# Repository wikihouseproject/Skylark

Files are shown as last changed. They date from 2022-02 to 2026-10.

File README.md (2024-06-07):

# Skylark
A block-based WikiHouse timber building system, developed for 1-3 storey construction.
For more information, product guides, and support services please visit www.wikihouse.cc

#### This work is licensed under a <a rel="license" href="http://creativecommons.org/licenses/by-sa/4.0/">Creative Commons Attribution-ShareAlike 4.0 International License</a>.

Developed and maintained by the friendly team at Open Systems Lab (www.opensystemslab.io).

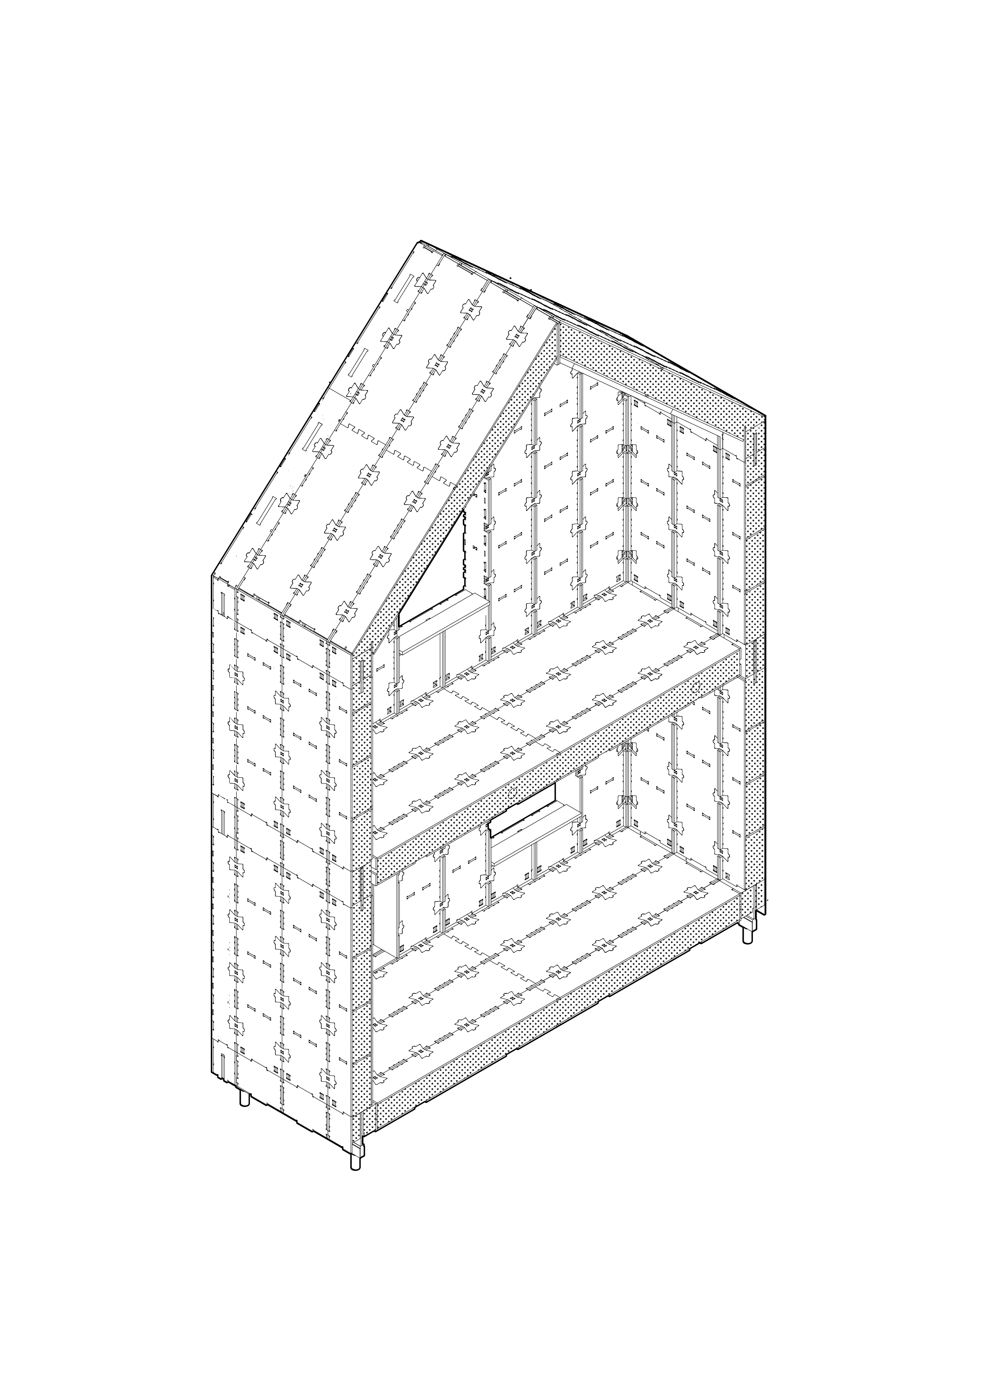
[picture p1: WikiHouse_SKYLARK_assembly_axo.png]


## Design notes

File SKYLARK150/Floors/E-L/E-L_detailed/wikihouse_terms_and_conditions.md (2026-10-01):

# WikiHouse Skylark Blocks — CNC Manufacturing Files

## WikiHouse Skylark System

**Website:** [www.wikihouse.cc](https://www.wikihouse.cc)
Developed by **Open Systems Lab**

> By using this information you agree to the full WikiHouse Terms of Use:
> [https://www.wikihouse.cc/terms](https://www.wikihouse.cc/terms)

---

## CNC Information

All geometry has tolerance offsets pre-applied for manufacture. "Dog-bone" pockets have been added on internal corners to mitigate any filleting caused by the router bit. Follow the layer information below for guidance on recommended settings.

---

## Layer Information

| Layer | Description |
|---|---|
| `DONOTCUT` | Information for instruction purposes only |
| `0_SHEET_SPRUCEPLY_2440X1220X18` | Plywood material boundary for reference |
| `1_ANYTOOL_1MMDEEP_LABELS` | Text labels — convert to curves and engrave at 1 mm depth |
| `2_ANYTOOL_1MMDEEP_SCREWMARKS` | Marker "dinks" for nails/screws during assembly — pre-mark using 2–3 mm bit |
| `3_ANYTOOL_CUTTHROUGH_INSIDE` | Internal slots — cut through inside line |
| `4_ANYTOOL_CUTTHROUGH_OUTSIDE` | External profile of parts — cut through outside line |
| `5_ANYTOOL_HALF_MILL_9MM_INSIDE` | Mill out area to 9 mm depth |

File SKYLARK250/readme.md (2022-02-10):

# Skylark 250 series
Skylark 250 is the main WikiHouse building system. The structure is deep enough to contain 250mm of wall insulation and it is intended for use in 1-3 storey detached buildings. For more information, view the design guide (https://www.wikihouse.cc/guides/design).

BY USING THIS INFORMATION YOU AGREE 
TO THE FULL WIKIHOUSE TERMS OF USE:
https://www.wikihouse.cc/terms

WikiHouse information and files are shared ‘as is’, without warranties, guarantees or certifications of any kind, express or implied. This includes, without limitation, warranties that the content is accurate, complete, free of defects, fit for a particular purpose or non-infringing in relation to the use of WikiHouse information or the results of such use. You are wholly responsible for checking WikiHouse information and for using WikiHouse information in a safe way, and for satisfying yourself that you meet all relevant regulations, including planning regulations, building codes and health & safety legislation; as well as for working with appropriate equipment and materials and appropriately competent persons. Every project should always be checked by a structural engineer. For more specific advice, the End User should engage relevant qualified professionals or competent persons.

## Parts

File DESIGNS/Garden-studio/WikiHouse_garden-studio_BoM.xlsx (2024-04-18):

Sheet: Garden room BoM (standard)
Project name
Customer name
Project status
Delivery address
Building Type | Garden room |  |  |  |  | Key: | Materials
Gross Internal Area (m2) | 10.8 |  |  |  |  |  | Labour
Updated | 2024-04-15
Note: This is a template for project estimation purposes only. Specified items listed here are subject to prices changes, and these figures do not represent a quote or guaranteed build price.
Bill of Materials
 | Description | Suggested specification | Total quantity | Unit | Cost per unit | Total cost | Est. mass (kg) | Embodied CO2 (kgCOe)
FOUNDATIONS
Piles | 1000mm round ground screws, securing L brackets | Self-installed ground screws (https://thegroundscrewshop.co.uk/calculator/) | 18 | No. | £30.00 | £540 | - | -
Base frame / sole plate | 200x75mm C24 timber joist | 200x75 (195x72mm finished size) C24 treated timber joist (https://www.stoketimber.com/product/75-x-200-69-x-195-finished-sizes-treated-c16-grade-timber-joists/) | 14.4 | m | £10.00 | £144 | - | -
Timber decking | Non-slip treated softwood decking | TBC | 5 | m2 | £70.00 | £350 | 60 | -61.8
Deck base frame | C24 timber joists | 100x50mm c24 treated timber joists | 22.5 | m | £8.00 | £180 | - | -
Piles to support deck | 800mm round ground screws, securing brackets | Self-installed ground screws (https://thegroundscrewshop.co.uk/calculator/) | 10 | No. | £30.00 | £300 | - | -
Foundation install |  |  |  | person/day |  | £0
Deck install |  |  |  | person/day |  | £0
 |  |  |  |  |  | £1514
STRUCTURE
WikiHouse chassis | 18mm OSB3 2440x1220mm sheets | SterlingOSB3 Zero | 70 | sheets | £19.00 | £1330 | 1953 | -3229.411248
Wall insulation | 200mm thick coverage soft-fill batts | Rockwool | 150 | m2 | £15.00 | £2250 | 600 | 78
Floor insulation | 150mm thick coverage soft-fill batts | Rockwool | 14.4 | m2 | £15.00 | £216 | 57.6 | 7.488
Under floor insulation | 40mm woodfibre board insulation | Pavatherm Pavatex 575x40mm | 10.08 | m2 | £15.00 | £151.2 | - | -
Roof insulation | 150mm thick coverage soft-fill batts | Rockwool | 14.4 | m2 | £15.00 | £216 | 57.6 | 7.488
Fixings | Brad nails for manufacturer | No. 18 brad nails 35mmx1.5mm | 4.4 | packs | £6.00 | £26.4 | - | -
CNC machining & manufacturing costs | By manufacturer | 3 axis CNC with 1.22 x 2.44m bed | 70 | sheets | £37.50 | £2625
Offsite Block assembly | By manufacturer |  | 2 | person/day | £200.00 | £400
Chassis assembly | By contractor/manufacturer |  |  | person/day |  | £0
 |  |  |  |  |  | £7214.6
SEAL
Breather membrane and tape | Weatherproof breather membrane | DuPont Tyvek UV Facade Protective Membrane (https://www.insulationsuperstore.co.uk/product/tyvek-uv-facade-protective-membrane-from-dupont-50m-x-15m-roll.html) | 55 | m2 | £6.00 | £330 | - | -
Airtight tape | Airtight vapour seal tape | Tescon or similar | 50 | m | £1.00 | £50 | - | -
Window | 600x1500mm double glazed tilt & turn | Pine frame double glazed (https://windowsarchitects.co.uk/product/configure/) | 1 | No. | £500.00 | £500 | 37 | -
External door | Timber frame double glazed french doors | w2400mm x h2000mm timber frame double glazed french doors | 1 | No. | £2200.00 | £2200 | 165 | -
Skylight | Double glazed fixed rooflight | 1300x400mm double glazed fixed rooflight | 1 | No. | £750.00 | £750 | - | -
EPDM roofing membrane | Dry-apply EPDM rubber membrane | 1.2mm EPDM rubber membrane single sheet (https://www.rubber4roofs.co.uk/classicbond-one-piece-epdm-rubber-roof-covering-1-20mm) | 15 | m2 | £11.00 | £165 | - | -
External membrane install |  |  |  | person/day |  | £0
Airtight tape install |  |  |  | person/day |  | £0
Window, door & rooflight install |  |  |  | person/day |  | £0
 |  |  |  |  |  | £3995
EXTERNAL FINISHES
Rainscreen cladding | Softwood vertical cladding boards | 50x25mm British larch cladding, planed | 35 | m2 | £60.00 | £2100 | 770 | -793.1
Cladding battens | Treated battens and counterbattens | 25mm x 50mm treated softwood (@600 ctrs) | 220 | m | £1.00 | £220 | 151.25 | -155.7875
Roofing material | Sedum blanket green roof system | Sky Garden sedum blanket system (https://www.roofingsuperstore.co.uk/product/sky-garden-sedum-blanket-system-kit-15m2.html) | 15 | m2 | £50.00 | £750 | - | -
Roofing edging | Aluminium sedum roof edging | 80mm high edge strip | 15.6 | m | £17.00 | £265.2 | - | -
Gutters | Steel half-round gutter | 100mm galvanised steel half-round | 5 | m | £15.00 | £75 | - | -
Downpipes | 2.5m steel round downpipe with header | 75mm galvanised steel downpipe (https://www.roofingmegastore.co.uk/lindab-steel-guttering-downpipe.html) | 5 | m | £35.00 | £175 | - | -
Window reveals | Softwood 100mm deep reveals | 100x20mm British larch cladding, planed | 20.4 | m | £5.00 | £102 | 28.05 | -28.8915
Flashings and accessories | Aluminium flashing and sealing tape | Aluminium window head flashing | 10 | m | £10.00 | £100 | - | -
Roofing install |  |  |  | person/day |  | £0
Cladding install |  |  |  | person/day |  | £0
 |  |  |  |  |  | £3787.2
SERVICES
Space heating | Electrical underfloor heating and thermostat | 150W/m2 system plus underlay and thermostat (10m2) (https://www.theunderfloorheatingstore.com/products/prowarm-electric-underfloor-heating-150w-mat-kit) | 1 | No. | £300.00 | £300 | - | -
Electrics and lighting | Garden room electrical kit | Fuse box, 2x double sockets, LED downlights, dimmer light switch | 1 | Configuration | £100.00 | £100 | - | -
External lighting | Up & down lights | Chrome external LED up & down lights | 2 | No. | £25.00 | £50 | - | -
PV solar system (Optional) | Optional solar PV system and inverter | TBC | 1 | No. |  | £0 | - | -
Electrical & heating install |  |  |  | person/day |  | £0
Solar panels install (Optional) |  |  |  | person/day |  | £0
 |  |  |  |  |  | £450
INTERNAL FIT OUT & FINISHES
Internal lining | 15mm woodwool lining boards | 2100mm x 600mm woodwool boards (https://www.savolit.co.uk/product/savolit-plus-woodwool-boards/) | 37.2 | m2 | £10.00 | £372 | - | -
Chipboard floor covering | 18mm tongue & groove flooring | Chipboard Tongue & groove Floorboard 2.4mx600mmx18mm (https://www.diy.com/departments/p5-tgv4-chipboard-tongue-groove-floorboard-l-2-4m-w-600mm-t-18mm/1696267_BQ.prd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) | 10.8 | m2 | £10.00 | £108 | - | -
Flooring | Engineered wood flooring | 14mm thick natural oak floating floor | 10.8 | m2 | £45.00 | £486 | - | -
Internal window reveals | 18mm plywood reveals | 200x18mm birch plywood reveals | 13 | m | £5.00 | £65 | - | -
Shelving & cabinetry | Optional custom 18mm plywood shelving unit | TBC | 1 | No. | £0.00 | £0 | 27.9 | -46.1344464
Flooring labour |  |  |  | person/day |  | £0
Internal finishes |  |  |  | person/day |  | £0
 |  |  |  |  |  | £1031
SELF-BUILD ESTIMATE (ex VAT)* |  |  |  |  |  | £17991.8 | 3907.4 | -4222.148694
Contingency (10%) |  |  |  |  |  | £1799.18
INSTALL ESTIMATE (ex VAT)* |  |  |  |  |  | £0 | kg | kgCO2e
TOTAL ESTIMATE* |  |  |  |  |  | £19790.98
VAT |  |  |  |  |  | £3958.196
*Build estimates for materials and labour, excluding VAT, fees, profits, overheads, contractor's prelims, transportation and landscaping

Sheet: Garden room blocks list (standa
Project name
Customer name
Delivery address
Skylark Cutting List Estimate
Name | Skylark_series | Type | Latest release | No. of blocks | Total sheets | Total insulation (m2) | Width (mm) | Length (mm) | Height (mm) | Est. mass(kg) | Structural Timber | Sheet Quantity | Insulation (m2) | Insulation Type | Fixings
SKYLARK200_CORNER-S | 200 | Wall | 0.2.2 | 4 | 4 | 2.24 | 268 | 268 | 2100 | 21 | 18mm structural OSB3 or plywood | 1 | 0.56 | Soft-fill batts | Brad nails
SKYLARK150_FLOOR-XXXS-0 | 150 | Floor | 0.2.2 | 7 | 14 | 14.84 | 2936 | 600 | 200 | 58 | 18mm structural OSB3 or plywood | 2 | 2.12 | Soft-fill batts | Brad nails
SKYLARK150_END-XXXS-0 | 150 | Floor | 0.2.2 | 2 | 2.4 | 0.12 | 2936 | 268 | 200 | 25 | 18mm structural OSB3 or plywood | 1.2 | 0.06 | Soft-fill batts | Brad nails
SKYLARK150_ROOF-XXXS | 200 | Roof | 0.2.2 | 6 | 12 | 12.72 | 2936 | 600 | 230 | 37 | 18mm structural OSB3 or plywood | 2 | 2.12 | Soft-fill batts | Brad nails
SKYLARK150_VERGE-XXXS | 200 | Roof | 0.2.2 | 2 | 2.6 | 1.9 | 2936 | 268 | 282 | 59 | 18mm structural OSB3 or plywood | 1.3 | 0.95 | Soft-fill batts | Brad nails
SKYLARK200_WALL-S | 200 | Wall | 0.2.2 | 17 | 25.5 | 21.42 | 268 | 600 | 2100 | 35 | 18mm structural OSB3 or plywood | 1.5 | 1.26 | Soft-fill batts | Brad nails
SKYLARK200_DOOR-S2 | 200 | Windows and doorways | 0.2.2 | 1 | 3 | 0.16 | 268 | 600 | 2100 | 41 | 18mm structural OSB3 or plywood | 3 | 0.16 | Soft-fill batts | Brad nails
SKYLARK200_WINDOW-S3 | 200 | Windows and doorways | 0.2.2 | 1 | 1.3 | 0.2 | 268 | 600 | 2100 | 21 | 18mm structural OSB3 or plywood | 1.3 | 0.2 | Soft-fill batts | Brad nails
SKYLARK150_SKYLIGHT-XXXS-0 | 150 | Roof | 0.2.2 | 1 | 2 | 1 | 268 | 2936 | 230 | 29 | 18mm structural OSB3 or plywood | 2 | 1 | Soft-fill batts | Brad nails
SKYLARK200_TIES | 200 | Windows and doorways | 0.2.2 | 3 | 3 | 0 | 90 | 154 | 18 | 0 | 18mm structural OSB3 or plywood | 1 | 0 | Soft-fill batts | Brad nails
TOTAL |  |  |  | 44 | 69.8 | 54.6

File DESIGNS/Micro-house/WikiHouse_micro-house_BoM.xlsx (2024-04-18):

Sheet: Microhouse BoM (trailer)
Project name
Customer name
Project status
Delivery address
Building Type | Microhouse (1 bed) |  |  |  |  | Key: | Materials
Gross Internal Area (m2) | 26.0 |  |  |  |  |  | Labour
Updated | 2024-04-16
Note: This is a template for project estimation purposes only. Specified items listed here are subject to prices changes, and these figures do not represent a quote or guaranteed build price.
Bill of Materials
 | Description | Suggested specification | Total quantity | Unit | Cost per unit | Total cost | Est. mass (kg) | Embodied CO2 (kgCOe)
FOUNDATIONS
Trailer | Custom 'tiny house' trailer system | TBC | 1 | No. | £6000.00 | £6000 | - | -
Base frame / sole plate | 200x75mm C24 timber joist | 250x75 (195x72mm finished size) C24 treated timber joist (https://www.stoketimber.com/product/75-x-200-69-x-195-finished-sizes-treated-c16-grade-timber-joists/) | 25 | m | £10.00 | £250 | - | -
Timber decking | Non-slip treated softwood decking | TBC | 20 | m2 | £70.00 | £1400 | 240 | -247.2
Deck base frame | C24 timber joists | 100x50mm c24 treated timber joists | 20 | m | £8.00 | £160 | - | -
Piles to support deck | 800mm round ground screws, securing brackets | Self-installed ground screws (https://thegroundscrewshop.co.uk/calculator/) | 12 | No. | £30.00 | £360 | - | -
Foundation install |  |  | 10 | person/day |  | £0
Deck install |  |  | 2 | person/day |  | £0
 |  |  |  |  |  | £8170
STRUCTURE
WikiHouse chassis | 18mm OSB3 2440x1220mm sheets | SterlingOSB3 Zero | 190 | sheets | £19.00 | £3610 | 5301 | -8765.544816
Ridge beam | Glulam ridge beam | Glulam beam 400x90mm | 9.5 | m | £60.00 | £570 | 78.375 | -80.72625
Wall insulation | 200mm thick soft-fill batts | SisalWool natural fibre (2x 100mm thickness) | 52.5 | m2 | £25.00 | £1312.5 | - | -
Floor insulation | 200mm thick soft-fill batts | SisalWool natural fibre (2x 100mm thickness) | 33.3 | m2 | £25.00 | £832.5 | - | -
Under-floor insulation | 40mm woodfibre board insulation | Pavatherm Pavatex 1100x575x40mm | 26 | m2 | £15.00 | £390 | - | -
Roof insulation | 200mm thick soft-fill batts | SisalWool natural fibre (2x 100mm thickness) | 61.8 | m2 | £25.00 | £1545 | - | -
Internal ceiling insulation lining | 25mm wood wool board | 25mm SKANDA Savolit Plus | 36 | m3 | £15.00 | £540 | - | -
Fixings | Brad nails for manufacturer | No. 18 brad nails 35mmx1.5mm | 9 | packs | £6.00 | £54 | - | -
CNC machining & manufacturing costs | By contractor/manufacturer | 3 axis CNC with 1.22 x 2.44m bed | 190 | sheets | £40.00 | £7600
Offsite Block assembly | By contractor/manufacturer |  | 15 | person/day | £200.00 | £3000
Chassis assembly | By contractor/manufacturer |  | 16 | person/day |  | £0
 |  |  |  |  |  | £19454
SEAL
Breather membrane and tape | Weatherproof breather membrane | DuPont Tyvek UV Facade Protective Membrane (https://www.insulationsuperstore.co.uk/product/tyvek-uv-facade-protective-membrane-from-dupont-50m-x-15m-roll.html) | 120 | m2 | £6.00 | £720 | - | -
Window seal tape | Watertight window seal tape | Pro Clima Contega Solido Exo or similar | 40.6 | m | £3.00 | £121.8 | - | -
Window 1 | w1106 x h1900mm double glazed inward opening | Aluclad double glazed tilt & turn window | 2 | No. | £1300.00 | £2600 | - | -
Window 2 | w1106 x h1470mm double glazed inward opening | Aluclad double glazed tilt & turn window | 1 | No. | £1100.00 | £1100 | - | -
Window 3 | w500 x h1470mm double glazed inward opening | Aluclad double glazed tilt & turn window | 1 | No. | £900.00 | £900 | - | -
Window 4 | w500 x h870mm double glazed inward opening | Aluclad double glazed tilt & turn window | 1 | No. | £600.00 | £600 | - | -
External door with side-light | w1106 x h1900mm double glazed external door with w590 x h1930mm side-light | Aluclad glazed door with double glazed side-light | 1 | No. | £2000.00 | £2000 | - | -
Skylight | 1000x1259mm double glazed openable rooflight | Aluminium frame double glazed openable rooflight | 2 | No. | £1700.00 | £3400 | - | -
Base underboards | Moisture and rodent resistant underboards below suspended timber floor | 6mm Fluted Polypropylene (Correx) Sheet | 26 | m2 | £8.00 | £208 | - | -
External membrane install |  |  | 1 | person/day |  | £0
Additional insulation and airtightness install |  |  | 6 | person/day |  | £0
Window, door & rooflight install |  |  | 6 | person/day |  | £0
 |  |  |  |  |  | £11649.8
EXTERNAL FINISHES
Rainscreen cladding | Softwood vertical cladding boards | 50x25mm British larch cladding, planed | 62 | m2 | £60.00 | £3720 | 1364 | -1404.92
Cladding battens | Treated battens and counterbattens | 25mm x 50mm treated softwood (@600 ctrs) | 220 | m | £1.00 | £220 | 151.25 | -155.7875
Roofing material | Standing seam profile steel panels | Tata Catnic urban or similar | 47 | m2 | £50.00 | £2350 | - | -
Roof battens | Treated battens and counterbattens | 25mm x 50mm treated softwood (@600 ctrs) | 160 | m | £2.50 | £400 | - | -
Ridge capping | Galvanised steel ridge cap | Aluminium Wall Coping and corner angles, black | 10 | m | £30.00 | £300 | - | -
Gutters | Half-round galvanised steel gutters | Gutter and horizontal drain kit | 20 | m | £15.00 | £300 | - | -
Rainwater downpipes | Steel round downpipe with hopper | 100mm galvanised steel downpipe (https://www.roofingmegastore.co.uk/lindab-steel-guttering-downpipe.html) | 5 | m | £35.00 | £175 | - | -
Window reveals | 100mm deep reveals | 100mm deep aluminium window reveals | 40 | m | £20.00 | £800 | - | -
Flashings and accessories | Aluminium flashing and sealing tape | Window and eaves flashing | 30 | m | £10.00 | £300 | - | -
Roofing install |  |  | 2 | person/day |  | £0
Cladding install |  |  | 4 | person/day |  | £0
 |  |  |  |  |  | £8565
SERVICES
Space heating | Electrical panel heaters | Adax 600W slimline panel heater | 2 | No. | £200.00 | £400 | - | -
Heated towel rail | Wall mounted electrically heated rail | TBC | 1 | No. | £100.00 | £100 | - | -
Water heating | Hot water cylinder | Joule ThermaQ hot water cylinder | 1 | No. | £600.00 | £600 | - | -
Expansion vessel | Expansion vessel for water system | Joule expansion vessel | 1 | No. | £300.00 | £300 | - | -
MVHR unit and extraction vents | Decentralised micro-MVHR system | LUNOS E² ( A PAIR) (https://shopuk.partel.com/products/e2-a-pair-inc-transformer-controller?variant=29634640248876) | 1 | No. | £1300.00 | £1300 | - | -
Bathroom extraction unit | Extraction fan system with heat recovery | LUNOS EGO (https://shopuk.partel.com/collections/ventilation-with-heat-recovery/products/e-go-inc-transformer-controller) | 1 | No. | £1000.00 | £1000
Electrics | Electrical fixtures, switches, fuses, sockets | TBC | 1 | Configuration | £150.00 | £150 | - | -
Fire alarm | Multidetector sounder base | Aico or similar | 1 | No. | £60.00 | £60 | - | -
Fire alarm | Smoke detector sounder base | Aico or similar | 1 | No. | £40.00 | £40 | - | -
Lighting | Pendants, spotlights, external up & down lights | TBC | 1 | Configuration | £300.00 | £300 | - | -
Plumbing, soil pipe and drains | Hot and cold water plumbing, drains, air admittance valve | TBC | 1 | Configuration | £400.00 | £400 | - | -
Toilets/WC(s) | Wall-hung toilet system | TBC | 1 | No. | £250.00 | £250 | - | -
Shower(s) | Walk-in shower with tray | TBC | 1 | No. | £400.00 | £400 | - | -
Basins/sinks | Wall-hung bathroom sink | TBC | 1 | No. | £150.00 | £150 | - | -
Kitchen sink | TBC | TBC | 1 | No. | £150.00 | £150 | - | -
PV solar system (Optional) | Optional solar PV system and inverter | TBC | 1 | No. | £0.00 | £0 | - | -
Electrical & heating install |  |  | 2 | person/day |  | £0
Plumbing install |  |  | 2 | person/day |  | £0
Solar panels install (Optional) |  |  | 2 | person/day |  | £0
 |  |  |  |  |  | £5600
INTERNAL FIT OUT & FINISHES
Internal wall framing | Traditional timber stud framing | 100x50mm timber stud framing | 11 | m2 | £50.00 | £550 | - | -
Internal lining and skirting | 12mm plywood with skirting | 12mm WBP birch plywood | 34 | m2 | £15.00 | £510 | - | -
Internal bathroom lining and skirting | 12.5 moisture-resistant plasterboard | TBC | 11 | m2 | £15.00 | £165 | - | -
Chipboard floor covering | 18mm tongue & groove flooring | Chipboard Tongue & groove Floorboard 2.4mx600mmx18mm (https://www.diy.com/departments/p5-tgv4-chipboard-tongue-groove-floorboard-l-2-4m-w-600mm-t-18mm/1696267_BQ.prd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) | 26 | m2 | £10.00 | £260 | - | -
Hard flooring | Engineered wood flooring downstairs | 14mm thick natural oak floating floor | 21 | m2 | £45.00 | £945 | - | -
Mezzanine/loft | Traditional timber joist framing with ply sheathing | 100x50mm timber joists with plywood sheathing | 7 | m2 | £50.00 | £350 | - | -
Bathroom tiles | Porcelain bathroom floor tiles and grouting | Hexagonal bathroom tile mat and grouting | 5 | m2 | £45.00 | £225 | - | -
Internal window reveals | 18mm plywood reveals | 200x18mm birch plywood reveals | 40 | m | £5.00 | £200 | - | -
Internal doors | 838x1981mm internal door | 30min F/C Ply finish 44mm thick 838x1981mm Door | 2 | No. | £80.00 | £160 | - | -
Loft ladder | Wall mounted vertical loft ladder | TBC | 1 | No. | £60.00 | £120 | - | -
Fitted wardrobes | Custom 18mm plywood wardrobe units | TBC | 1 | No. | £0.00 | £0 | - | -
Kitchen units | Custom kitchen design | TBC | 1 | No. | £0.00 | £0 | - | -
Internal Partitions labour |  |  | 2 | person/day |  | £0
Flooring labour |  |  | 2 | person/day |  | £0
Kitchen install |  |  | 2 | person/day |  | £0
Internal finishes, painting, & decorating |  |  | 4 | person/day |  | £0
 |  |  |  |  |  | £3485
SELF-BUILD ESTIMATE (ex VAT)* |  |  |  |  |  | £56923.8 | 7134.625 | -10654.17857
Contingency (10%) |  |  |  |  |  | £5692.38
INSTALL ESTIMATE (ex VAT)* |  |  |  |  |  | £0 | kg | kgCO2e
TOTAL |  |  |  |  |  | £62616.18
VAT |  |  |  |  |  | £12523.236
*Build estimates for materials and labour, excluding VAT, fees, profits, overheads, contractor's prelims, transportation and landscaping

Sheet: Microhouse blocks list (trailer
Project name
Customer name
Delivery address
Skylark Cutting List Estimate
Name | Skylark_series | Type | Latest release | No. of blocks | Total sheets | Total insulation (m2) | Width (mm) | Length (mm) | Height (mm) | Est. mass(kg) | Structural Timber | Sheet Quantity | Insulation (m2) | Insulation Type | Fixings
SKYLARK200_END-XXS-0 | 250 | Floor | 0.2.2 | 2 | 3 | 1.8 |  |  |  |  | 18mm structural OSB3 or plywood | 1.5 | 0.9 | Soft-fill batts | Brad nails
SKYLARK200_FLOOR-XXS1-0 | 250 | Floor | 0.2.2 | 15 | 39 | 31.5 |  |  |  |  | 18mm structural OSB3 or plywood | 2.6 | 2.1 | Soft-fill batts | Brad nails
SKYLARK200_CORNER-S | 250 | Wall | 0.2.2 | 4 | 4 | 2.4 |  |  |  |  | 18mm structural OSB3 or plywood | 1 | 0.6 | Soft-fill batts | Brad nails
SKYLARK200_WALL-G42-1 | 250 | Wall | 0.2.2 | 2 | 2 | 2 |  |  |  |  | 18mm structural OSB3 or plywood | 1 | 1 | Soft-fill batts | Brad nails
SKYLARK200_WALL-G42-2 | 250 | Wall | 0.2.2 | 2 | 2.2 | 2 |  |  |  |  | 18mm structural OSB3 or plywood | 1.1 | 1 | Soft-fill batts | Brad nails
SKYLARK200_WALL-G42-3R1 | 250 | Wall | 0.2.2 | 2 | 3.6 | 2.6 |  |  |  |  | 18mm structural OSB3 or plywood | 1.8 | 1.3 | Soft-fill batts | Brad nails
SKYLARK200_WALL-G42-6 | 250 | Wall | 0.2.2 | 2 | 2 | 2 |  |  |  |  | 18mm structural OSB3 or plywood | 1 | 1 | Soft-fill batts | Brad nails
SKYLARK200_WALL-G42-7 | 250 | Wall | 0.2.2 | 2 | 2 | 2 |  |  |  |  | 18mm structural OSB3 or plywood | 1 | 1 | Soft-fill batts | Brad nails
SKYLARK200_WALL-S | 250 | Wall | 0.2.2 | 27 | 40.5 | 35.1 |  |  |  |  | 18mm structural OSB3 or plywood | 1.5 | 1.3 | Soft-fill batts | Brad nails
SKYLARK200_WALL-S1 | 250 | Wall | 0.2.2 | 2 | 3 | 2.6 |  |  |  |  | 18mm structural OSB3 or plywood | 1.5 | 1.3 | Soft-fill batts | Brad nails
SKYLARK200_DOOR-S1 | 250 | Windows and doorways | 0.2.2 | 2 | 3 | 0.6 |  |  |  |  | 18mm structural OSB3 or plywood | 1.5 | 0.3 | Soft-fill batts | Brad nails
SKYLARK200_DOOR-S2 | 250 | Windows and doorways | 0.2.2 | 1 | 2 | 0.5 |  |  |  |  | 18mm structural OSB3 or plywood | 2 | 0.5 | Soft-fill batts | Brad nails
SKYLARK200_WINDOW-S1 | 250 | Windows and doorways | 0.2.2 | 1 | 1.5 | 0.2 |  |  |  |  | 18mm structural OSB3 or plywood | 1.5 | 0.2 | Soft-fill batts | Brad nails
SKYLARK200_WINDOW-S3 | 250 | Windows and doorways | 0.2.2 | 1 | 1.3 | 0.2 |  |  |  |  | 18mm structural OSB3 or plywood | 1.3 | 0.2 | Soft-fill batts | Brad nails
SKYLARK200_WINDOW-S4 | 250 | Windows and doorways | 0.2.2 | 1 | 1.9 | 0.3 |  |  |  |  | 18mm structural OSB3 or plywood | 1.9 | 0.3 | Soft-fill batts | Brad nails
SKYLARK200_ROOF-42-XXS1 | 250 | Roof | 0.2.2 | 26 | 46.8 | 54.6 |  |  |  |  | 18mm structural OSB3 or plywood | 1.8 | 2.1 | Soft-fill batts | Brad nails
SKYLARK200/SKYLIGHT-XXS1 | 250 | Roof | 0.2.2 | 2 | 10 | 7.2 |  |  |  |  | 18mm structural OSB3 or plywood | 5 | 3.6 | Soft-fill batts | Brad nails
TIES | 250 | TIES | 0.2.2 | 6 | 18 | 25.2 |  |  |  |  | 18mm structural OSB3 or plywood | 3 | 4.2 | Soft-fill batts | Brad nails
TOTAL |  |  |  | 100 | 185.8 | 172.8

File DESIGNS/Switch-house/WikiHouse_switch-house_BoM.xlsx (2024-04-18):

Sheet: Switch house BoM (standard)
Project name
Customer name
Project status
Delivery address
Building Type | Switch house (3 bed) |  |  |  |  | Key: | Materials
Gross Internal Area (m2) | 104.0 |  |  |  |  |  | Labour
Updated | 2024-04-16
Note: This is a template for project estimation purposes only. Specified items listed here are subject to prices changes, and these figures do not represent a quote or guaranteed build price.
Bill of Materials
 | Description | Suggested specification | Total quantity | Unit | Cost per unit | Total cost | Est. mass (kg) | Embodied CO2 (kgCOe)
FOUNDATIONS
Piles | Helical ground screws, securing L brackets | TBC | 43 | No. | £120.00 | £5160 | - | -
Base frame / sole plate | 250x75mm C24 timber joist | 250x75 (195x72mm finished size) C24 treated timber joist (https://www.stoketimber.com/product/75-x-200-69-x-195-finished-sizes-treated-c16-grade-timber-joists/) | 35 | m | £10.00 | £350 | - | -
Base frame / sole plate | 150x75mm C24 timber joist | 150x75 (145x72mm finished size) C24 treated timber joist (https://www.stoketimber.com/product/75-x-150mm-x-4-8m-c24-treated/) | 5.5 | m | £10.00 | £55 | - | -
Timber decking | Non-slip treated softwood decking | TBC | 12 | m2 | £70.00 | £840 | 144 | -148.32
Deck base frame | C24 timber joists | 100x50mm c24 treated timber joists | 22.5 | m | £8.00 | £180 | - | -
Piles to support deck | 800mm round ground screws, securing brackets | Self-installed ground screws (https://thegroundscrewshop.co.uk/calculator/) | 10 | No. | £30.00 | £300 | - | -
Foundation install |  |  | 10 | person/day |  | £0
Deck install |  |  | 2 | person/day |  | £0
 |  |  |  |  |  | £6885
STRUCTURE
WikiHouse chassis | 18mm OSB3 2440x1220mm sheets | SterlingOSB3 Zero | 520 | sheets | £19.00 | £9880 | 14508 | -23989.91213
Wall insulation | 250mm thick soft-fill batts | Mineral wool | 150 | m2 | £20.00 | £3000 | 750 | 97.5
Floor insulation | 270mm thick soft-fill batts | Mineral wool | 100 | m2 | £20.00 | £2000 | 500 | 65
Under-floor insulation | 40mm woodfibre board insulation | Pavatherm Pavatex 1100x575x40mm | 52 | m2 | £15.00 | £780 | - | -
Roof insulation | 270mm thick soft-fill batts | Mineral wool | 62 | m2 | £20.00 | £1240 | 124 | 16.12
Over-roof insulation | 100mm thick woodfibre board insulation | Pavatherm Pavatex 1100x600x100mm | 52 | m2 | £30.00 | £1560 | - | -
Fixings | Brad nails for manufacturer | No. 18 brad nails 35mmx1.5mm | 19.8 | packs | £6.00 | £118.8 | - | -
CNC machining & manufacturing costs | By contractor/manufacturer | 3 axis CNC with 1.22 x 2.44m bed | 520 | sheets | £40.00 | £20800
Offsite Block assembly | By contractor/manufacturer |  | 30 | person/day | £200.00 | £6000
Chassis assembly | By contractor/manufacturer |  | 50 | person/day |  | £0
 |  |  |  |  |  | £45378.8
SEAL
Party wall fire protection layer (for row house) | 100mm non-combustible insulation | 100mm thick mineral wool batts | 75 | m2 | £10.00 | £750 | -
Breather membrane and tape | Weatherproof breather membrane | DuPont Tyvek UV Facade Protective Membrane (https://www.insulationsuperstore.co.uk/product/tyvek-uv-facade-protective-membrane-from-dupont-50m-x-15m-roll.html) | 364 | m2 | £6.00 | £2184 | - | -
Window seal tape | Watertight window seal tape | Pro Clima Contega Solido Exo or similar | 60 | m | £3.00 | £180 | - | -
Window 1 | w1106 x h2370mm triple glazed inward opening | Aluclad triple glazed inward opening casement window | 3 | No. | £1700.00 | £5100 | - | -
Window 2 | w1106 x h1770mm triple glazed inward opening | Aluclad triple glazed inward opening casement window | 2 | No. | £1500.00 | £3000 | - | -
External door | w1106 x h2150mm composite external door with w1106 x h655mm toplight | Aluminium composite door with toplight | 1 | No. | £1500.00 | £1500 | - | -
Glazed door | w1106 x h1990mm triple glazed inward opening patio doors | Aluclad triple glazed inward opening patio doors | 2 | No. | £1500.00 | £3000 | - | -
Skylight 1 | 1800x528mm triple glazed fixed rooflight | Aluminium frame triple glazed fixed rooflight | 1 | No. | £750.00 | £750 | - | -
Skylight 2 | 1380x528mm triple glazed fixed rooflight | Aluminium frame triple glazed fixed rooflight | 1 | No. | £600.00 | £600 | - | -
Roofing membrane | Dry-apply EPDM rubber membrane | 1.2mm EPDM rubber membrane single sheet | 70 | m2 | £25.00 | £1750 | - | -
Base underboards | Moisture and rodent resistant underboards below suspended timber floor | 6mm Fluted Polypropylene (Correx) Sheet | 60 | m2 | £8.00 | £480 | - | -
External membrane install |  |  | 2 | person/day |  | £0
Additional insulation and airtightness install |  |  | 6 | person/day |  | £0
Window, door & rooflight install |  |  | 6 | person/day |  | £0
Airtightness testing | Blower-door test |  | 1 | person/day |  | £0
 |  |  |  |  |  | £18544
EXTERNAL FINISHES
Rainscreen cladding | Softwood vertical cladding boards | 50x25mm British larch cladding, planed | 70 | m2 | £60.00 | £4200 | 1540 | -1586.2
Cladding battens | Treated battens and counterbattens | 25mm x 50mm treated softwood (@600 ctrs) | 220 | m | £1.00 | £220 | 151.25 | -155.7875
Roofing material | Standing seam profile steel panels | Tata Catnic urban or similar | 60 | m2 | £50.00 | £3000 | - | -
Roof furrings | 3 degree timber furrings at 600mm centres | Timber furrings at 600mm centres | 90 | m | £2.50 | £225 | - | -
Parapet flashing | Aluminium parapet wall coping | Aluminium Wall Coping and corner angles, black | 32 | m | £30.00 | £960 | - | -
Gutters | Horizontal drain system for EPDM roof | Gutter and horizontal drain kit | 9.7 | m | £15.00 | £145.5 | - | -
Rainwater downpipes | Steel round downpipe with hopper | 100mm galvanised steel downpipe (https://www.roofingmegastore.co.uk/lindab-steel-guttering-downpipe.html) | 13 | m | £35.00 | £455 | - | -
Rainwater hoppers | Steel hopper unit | Regular square rainwater hopper (https://www.roofingmegastore.co.uk/lindab-guttering-regular-water-hopper-vatkr.html) | 2 | No. | £80.00 | £160 | - | -
Window reveals | 100mm deep reveals | 100x20mm British larch cladding, planed | 60 | m | £20.00 | £1200 | 82.5 | -84.975
Upper window railings | Steel external juliet balcony railings | 1300mm wide powdercoated balcony railings | 4 | No. | £100.00 | £400 | - | -
Flashings and accessories | Aluminium flashing and sealing tape | Aluminium window head flashing | 9.6 | m | £10.00 | £96 | - | -
Roofing install |  |  | 4 | person/day |  | £0
Cladding install |  |  | 8 | person/day |  | £0
 |  |  |  |  |  | £11061.5
SERVICES
Space heating | Electrical panel heaters | Adax 600W slimline panel heater | 6 | No. | £200.00 | £1200 | - | -
Heated towel rail | Wall mounted electrically heated rail | TBC | 1 | No. | £100.00 | £100 | - | -
Water heating | Hot water cylinder | Joule ThermaQ hot water cylinder | 1 | No. | £1200.00 | £1200 | - | -
Expansion vessel | Expansion vessel for water system | Joule expansion vessel | 1 | No. | £300.00 | £300 | - | -
MVHR unit, ducting and valves | MVHR system with full summer bypass | Greenwood, Lindab or similar with 125mm diameter ducting | 1 | No. | £1800.00 | £1800 | - | -
Electrics | Electrical fixtures, switches, fuses, sockets | TBC | 1 | Configuration | £250.00 | £250 | - | -
Fire alarm | Multidetector sounder base | Aico or similar | 1 | No. | £60.00 | £60 | - | -
Fire alarm | Smoke detector sounder base | Aico or similar | 4 | No. | £40.00 | £160 | - | -
Lighting | Pendants, spotlights, external up & down lights | TBC | 1 | Configuration | £600.00 | £600 | - | -
Plumbing, soil pipe and drains | Hot and cold water plumbing, drains, air admittance valve | TBC | 1 | Configuration | £500.00 | £500 | - | -
Toilets/WC(s) | Wall-hung toilet system | TBC | 3 | No. | £250.00 | £750 | - | -
Bath(s) | Bath/shower combo unit | TBC | 1 | No. | £500.00 | £500 | - | -
Shower(s) | Walk-in shower with tray | TBC | 1 | No. | £400.00 | £400 | - | -
Basins/sinks | Wall-hung bathroom sink | TBC | 3 | No. | £150.00 | £450 | - | -
Kitchen sink | TBC | TBC | 1 | No. | £150.00 | £150 | - | -
PV solar system (Optional) | Optional solar PV system and inverter | TBC | 1 | No. | £0.00 | £0 | - | -
Electrical & heating install |  |  | 4 | person/day |  | £0
Plumbing install |  |  | 5 | person/day |  | £0
Solar panels install (Optional) |  |  | 2 | person/day |  | £0
 |  |  |  |  |  | £8420
INTERNAL FIT OUT & FINISHES
Internal wall framing | Traditional timber stud framing | 100x50mm timber stud framing | 50 | m2 | £50.00 | £2500 | - | -
Internal lining and skirting | 12.5mm plasterboard with skirting | 12.5mm plasterboard | 350 | m2 | £15.00 | £5250 | - | -
Chipboard floor covering | 18mm tongue & groove flooring | Chipboard Tongue & groove Floorboard 2.4mx600mmx18mm (https://www.diy.com/departments/p5-tgv4-chipboard-tongue-groove-floorboard-l-2-4m-w-600mm-t-18mm/1696267_BQ.prd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) | 10.8 | m2 | £10.00 | £108 | - | -
Hard flooring | Engineered wood flooring downstairs | 14mm thick natural oak floating floor | 52 | m2 | £45.00 | £2340 | - | -
Carpet | Domestic thick pile carpet upstairs and on stairs | TBC | 45 | m2 | £40.00 | £1800 | - | -
Bathroom tiles | Porcelain bathroom floor tiles and grouting | Hexagonal bathroom tile mat and grouting | 7 | m2 | £45.00 | £315 | - | -
Internal window reveals | 18mm plywood reveals | 200x18mm birch plywood reveals | 13 | m | £5.00 | £65 | - | -
Internal doors | 838x1981mm internal door | 30min F/C Ply finish 44mm thick 838x1981mm Door | 6 | No. | £80.00 | £480 | - | -
Handrails / Balustrade | Wooden handrail with wall fixing | TBC | 1 | No. | £60.00 | £60 | - | -
Fitted wardrobes | Custom 18mm plywood wardrobe units | TBC | 2 | No. | £0.00 | £0 | - | -
Kitchen units | Custom kitchen design | TBC | 1 | No. | £0.00 | £0 | - | -
Internal Partitions labour |  |  | 4 | person/day |  | £0
Flooring labour |  |  | 4 | person/day |  | £0
Kitchen install |  |  | 2 | person/day |  | £0
Internal finishes, painting, & decorating |  |  | 6 | person/day |  | £0
 |  |  |  |  |  | £10418
SELF-BUILD ESTIMATE (ex VAT)* |  |  |  |  |  | £103207.3 | 17799.75 | -25786.57463
Contingency (10%) |  |  |  |  |  | £10320.73
INSTALL ESTIMATE (ex VAT)* |  |  |  |  |  | £0 | kg | kgCO2e
TOTAL |  |  |  |  |  | £113528.03
VAT |  |  |  |  |  | £22705.606
*Build estimates for materials and labour, excluding VAT, fees, profits, overheads, contractor's prelims, transportation and landscaping

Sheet: Switch house blocks list (stand
Project name
Customer name
Delivery address
Skylark Cutting List Estimate
Name | Skylark_series | Type | Latest release | No. of blocks | Total sheets | Total insulation (m2) | Width (mm) | Length (mm) | Height (mm) | Est. mass(kg) | Structural Timber | Sheet Quantity | Insulation (m2) | Insulation Type | Fixings
SKYLARK250_FLOOR-L-0 | 250 | Floor | 0.2.2 | 9 | 43.2 | 32.4 |  |  |  |  | 18mm structural OSB3 or plywood | 4.8 | 3.6 | Soft-fill batts | Brad nails
SKYLARK250_FLOOR-L-1 | 250 | Floor | 0.2.2 | 26 | 124.8 | 93.6 |  |  |  |  | 18mm structural OSB3 or plywood | 4.8 | 3.6 | Soft-fill batts | Brad nails
SKYLARK250_END-S1_simple#2 | 250 | Floor | 0.2.2 | 4 | 1.2 | 1 |  |  |  |  | 18mm structural OSB3 or plywood | 0.3 | 0.25 | Soft-fill batts | Brad nails
SKYLARK250_END-L-1 | 250 | Floor | 0.2.2 | 4 | 13.2 | 7.6 |  |  |  |  | 18mm structural OSB3 or plywood | 3.3 | 1.9 | Soft-fill batts | Brad nails
SKYLARK250_XFLOOR-L-0 | 250 | Floor | 0.2.2 | 1 | 6.2 | 3.6 |  |  |  |  | 18mm structural OSB3 or plywood | 6.2 | 3.6 | Soft-fill batts | Brad nails
SKYLARK250_END-L-0 | 250 | Floor | 0.2.2 | 2 | 6.6 | 3.8 |  |  |  |  | 18mm structural OSB3 or plywood | 3.3 | 1.9 | Soft-fill batts | Brad nails
SKYLARK250_CORNER-M | 250 | Wall | 0.2.2 | 4 | 5.2 | 3.2 |  |  |  |  | 18mm structural OSB3 or plywood | 1.3 | 0.8 | Soft-fill batts | Brad nails
SKYLARK250_WALL-XL | 250 | Wall | 0.2.2 | 46 | 115 | 82.8 |  |  |  |  | 18mm structural OSB3 or plywood | 2.5 | 1.8 | Soft-fill batts | Brad nails
SKYLARK250_WALL-M | 250 | Wall | 0.2.2 | 44 | 88 | 61.6 |  |  |  |  | 18mm structural OSB3 or plywood | 2 | 1.4 | Soft-fill batts | Brad nails
SKYLARK250_CORNER-XL | 250 | Wall | 0.2.2 | 4 | 7.2 | 4 |  |  |  |  | 18mm structural OSB3 or plywood | 1.8 | 1 | Soft-fill batts | Brad nails
SKYLARK250_DOOR-M1 | 250 | Windows and doorways | 0.2.2 | 2 | 4 | 0.8 |  |  |  |  | 18mm structural OSB3 or plywood | 2 | 0.4 | Soft-fill batts | Brad nails
SKYLARK250_WINDOW-M4 | 250 | Windows and doorways | 0.2.2 | 2 | 4.2 | 0.8 |  |  |  |  | 18mm structural OSB3 or plywood | 2.1 | 0.4 | Soft-fill batts | Brad nails
SKYLARK250_WINDOW-XL4 | 250 | Windows and doorways | 0.2.2 | 3 | 8.4 | 1.2 |  |  |  |  | 18mm structural OSB3 or plywood | 2.8 | 0.4 | Soft-fill batts | Brad nails
SKYLARK250_DOOR-XL1 | 250 | Windows and doorways | 0.2.2 | 1 | 2.5 | 0.4 |  |  |  |  | 18mm structural OSB3 or plywood | 2.5 | 0.4 | Soft-fill batts | Brad nails
SKYLARK250_FLOOR-S-1 | 250 | Floor | 0.2.2 | 4 | 16 | 11.6 |  |  |  |  | 18mm structural OSB3 or plywood | 4 | 2.9 | Soft-fill batts | Brad nails
SKYLARK250_SKYLIGHT-L-1 | 250 | Floor | 0.2.2 | 1 | 5 | 3.6 |  |  |  |  | 18mm structural OSB3 or plywood | 5 | 3.6 | Soft-fill batts | Brad nails
SKYLARK250_SKYLIGHT-L-2 | 250 | Floor | 0.2.2 | 1 | 5 | 3.6 |  |  |  |  | 18mm structural OSB3 or plywood | 5 | 3.6 | Soft-fill batts | Brad nails
SKYLARK250_FLOOR-L-0* | 250 | Floor | 0.2.2 | 6 | 28.8 | 21.6 |  |  |  |  | 18mm structural OSB3 or plywood | 4.8 | 3.6 | Soft-fill batts | Brad nails
SKYLARK250_PARAPET-M | 250 | Roof | 0.2.2 | 24 | 24 | 0 |  |  |  |  | 18mm structural OSB3 or plywood | 1 | 0 | Soft-fill batts | Brad nails
SKYLARK250_POST-M | 250 | Roof | 0.2.2 | 4 | 2 | 0 |  |  |  |  | 18mm structural OSB3 or plywood | 0.5 | 0 | Soft-fill batts | Brad nails
TIES | 250 | TIES | 0.2.2 | 6 | 6 | 0 |  |  |  |  | 18mm structural OSB3 or plywood | 1 | 0 | Soft-fill batts | Brad nails
TOTAL |  |  |  | 198 | 516.5 | 337.2

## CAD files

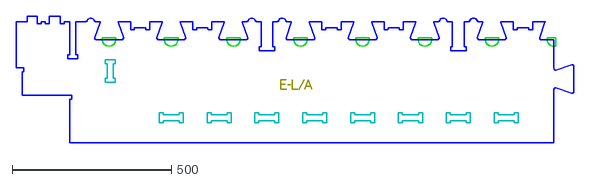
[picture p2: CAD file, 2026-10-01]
SKYLARK150/Floors/E-L/E-L_cnc/E-L-A.dxf
1747.5 x 397.5

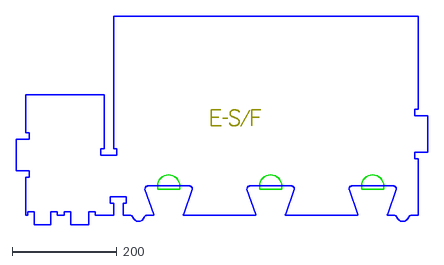
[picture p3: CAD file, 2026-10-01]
SKYLARK150/Floors/E-S/E-S_cnc/E-S-F.dxf
785.5 x 397.5

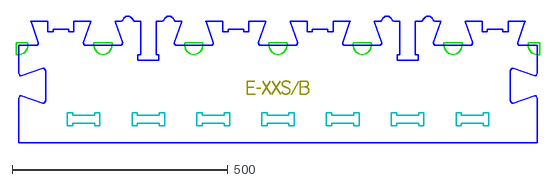
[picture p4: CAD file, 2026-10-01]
SKYLARK150/Floors/E-XXS/E-XXS_cnc/E-XXS-B.dxf
1212.5 x 293.5

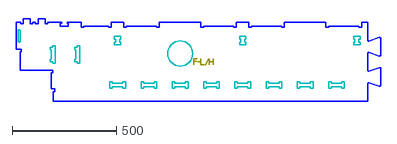
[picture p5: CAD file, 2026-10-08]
SKYLARK150/Floors/F-L/F-L_cnc/F-L-H.dxf
1747.5 x 397.5

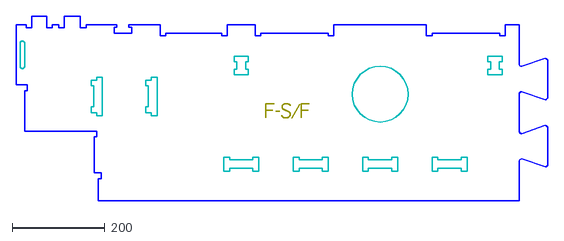
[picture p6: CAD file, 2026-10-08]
SKYLARK150/Floors/F-S/F-S_cnc/F-S-F.dxf
1147.5 x 397.5

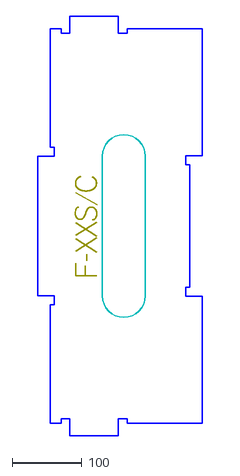
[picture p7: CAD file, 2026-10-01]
SKYLARK150/Floors/F-XXS/F-XXS_cnc/F-XXS-C.dxf
235.5 x 599.5

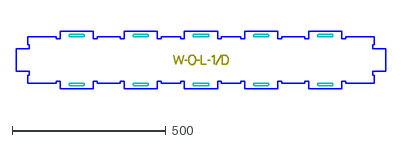
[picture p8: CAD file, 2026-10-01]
SKYLARK150/Openings/W-O-L-1/W-O-L-1_cnc/W-O-L-1-D.dxf
1199.5 x 185.6

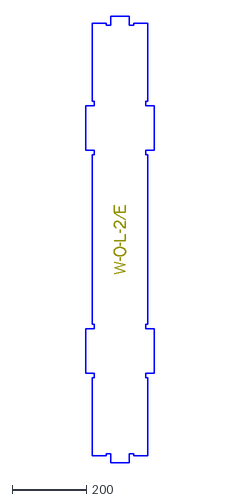
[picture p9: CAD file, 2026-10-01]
SKYLARK150/Openings/W-O-L-2/W-O-L-2_cnc/W-O-L-2-E.dxf
185.5 x 1199.5

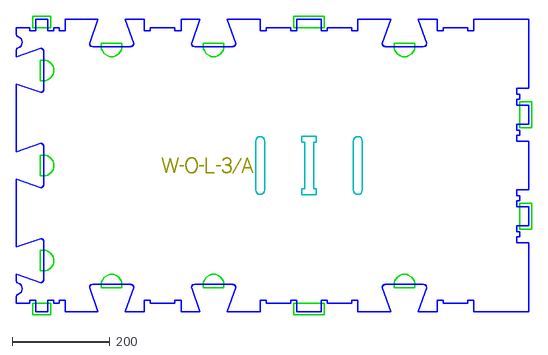
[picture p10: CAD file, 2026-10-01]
SKYLARK150/Openings/W-O-L-3/W-O-L-3_cnc/W-O-L-3-A.dxf
1056.0 x 612.5

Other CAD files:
SKYLARK150/Floors/E-L/E-L_detailed/E-L.dwg
SKYLARK150/Floors/E-S/E-S_detailed/E-S.dwg
SKYLARK150/Floors/E-XXS/E-XXS_detailed/E-XXS.dwg
SKYLARK150/Floors/F-L/F-L_detailed/F-L.dwg
SKYLARK150/Floors/F-S/F-S_detailed/F-S.dwg
SKYLARK150/Floors/F-XXS/F-XXS_detailed/F-XXS.dwg
SKYLARK150/Openings/W-O-L-1/W-O-L-1_detailed/W-O-L-1.dwg
SKYLARK150/Openings/W-O-L-2/W-O-L-2_detailed/W-O-L-2.dwg
SKYLARK150/Openings/W-O-L-3/W-O-L-3_detailed/W-O-L-3.dwg
SKYLARK150/Floors/E-L/E-L_cnc/E-L-B.dxf
SKYLARK150/Floors/E-L/E-L_cnc/E-L-C.dxf
SKYLARK150/Floors/E-L/E-L_cnc/E-L-D.dxf
SKYLARK150/Floors/E-L/E-L_cnc/E-L-E.dxf
SKYLARK150/Floors/E-L/E-L_cnc/E-L-F.dxf
SKYLARK150/Floors/E-L/E-L_cnc/E-L-G.dxf
SKYLARK150/Floors/E-L/E-L_cnc/E-L-H.dxf
SKYLARK150/Floors/E-L/E-L_cnc/E-L-I.dxf
SKYLARK150/Floors/E-L/E-L_cnc/E-L-J.dxf
SKYLARK150/Floors/E-L/E-L_cnc/E-L-K.dxf
SKYLARK150/Floors/E-L/E-L_cnc/E-L-L.dxf
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

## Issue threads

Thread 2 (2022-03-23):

Wall G blocks are not suitable for the right side of the X-axis

JennHuygen, 2022-03-23:
I tried to model with the G walls for the gabled roof to create a full wall that would support the gable roof. However, the G1-4 wall blocks do not mirror correctly. Consequently, you can only make the left side of the x-axis for the gabled roof walls.

To illustrate, this is how the gabled roof walls should look like, according to the chassis model:
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

However, if you model it yourself using the G1- G4 wall blocks, you can only create one side of the X-axis:
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

Therefore, to create the full wall for the gabled roof, you would need to copy and mirror the G1-4 blocks to the other side of the X-axis, but that doesn't give you the correct alignment:
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

JennHuygen, 2022-03-23:
Update: It's no longer an issue -- It turns out I wasn't using the correct mirroring tool in SketchUp.. learned something new :)

Closed 2022-03-23.

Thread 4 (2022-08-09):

Holes for ties between the Corner M and Wall M blocks do not match.

PetraVil, 2022-08-09:
Holes for ties between the Corner M and Wall M blocks do not match.

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

The same issue is between the Corner XL and Wall XL blocks.
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

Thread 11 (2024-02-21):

SKYLARK200_END-S don't match on WALLs in sketchup simple design kit

zwn, 2024-02-21:
`SKYLARK200_END-S-0` and `SKYLARK200_END-S-1` in simple sketchup kit have a wrong size of the notch offset:

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

The `FLOOR` parts have 43mm distance (cyan) while the `END` parts have 58mm (yellow). The `WALL` parts do not match on the `END` parts:

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

I believe 43mm is the correct value since the detailed parts are all 43mm.

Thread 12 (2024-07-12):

Issue with SKYLARK250_CORNER-S_cnc.dxf

VDobranov, 2024-07-12:
I believe here should be half-mills:
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

https://github.com/wikihouseproject/Skylark/blob/main/SKYLARK250/Walls/SKYLARK250_CORNER-S/SKYLARK250_CORNER-S_cnc.dxf

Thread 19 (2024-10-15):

Skylark250_END-XXS-0 cnc file not complete

clavko, 2024-10-15:
In comparison with the web version, the git version of the CNC file seems to have at least these issues:

END-RO\A missing a hole
END-RO\F missing some cutouts
END-SO\A missing a cutout
END-SO\B missing all cutouts

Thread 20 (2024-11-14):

Skylark 250 - Floor XXS - 1 - G element does not fit

clavko, 2024-11-14:
As the title says, the G element is the same as in Floor XXS 0 version, but the XXS-1 sides have holes for a plate similar to, say FLOOR-M-1-E.

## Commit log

2021-10-05 Create SKYLARK250_WINDOW-A1.3dm
    A 1.2m wide Skylark window block with a 1164mm(W) x 1418mm(H) opening
2021-10-06 File name change
    [SKYLARK250_WALL-M.3dm]
2021-10-19 New content upload
    [SKYLARK250_COMB-X1-M_detailed.3dm, SKYLARK250_COMB-X1-M_detailed.dwg, SKYLARK250_COMB-X1-M_detailed.skp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]
2021-10-20 Amended folder structure
    [SKYLARK250_COMB-X1-M_detailed.3dm, SKYLARK250_COMB-X1-M_detailed.dwg, SKYLARK250_COMB-X1-M_detailed.skp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]
2021-10-20 Simple 3D models added
    [SKYLARK250_COMB-X1-M_simple.3dm, SKYLARK250_COMB-X1-M_simple.dwg, SKYLARK250_COMB-X1-M_simple.skp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]
2022-01-05 Added WALL-M files
    [SKYLARK250_WALL-M_cnc.dxf]
2022-01-28 Updated package for release
    [SKYLARK250_COMB-X1-M_detailed.3dm, SKYLARK250_COMB-X1-M_detailed.dwg, SKYLARK250_COMB-X1-M_detailed.skp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]
2022-02-09 Initial release commit
    [SKYLARK250_COMB-A_END-X1_cnc.dxf, SKYLARK250_COMB-A_END-X1_detailed.3dm, SKYLARK250_COMB-A_END-X1_detailed.dwg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]
2022-02-10 Launch release commit
    [SKYLARK250_ROOF-G_cnc.dxf, SKYLARK250_design-kit_v0.1.0_simple.skp]
2022-02-10 Updated design kit
    [SKYLARK250_design-kit_v0.1.0_simple.skp]
2022-02-11 Updates and corrections to design kit
    [SKYLARK250 block list.xlsx]
2022-02-18 WALL-S/C incorrect length fixed
    [SKYLARK250_WALL-S_cnc.dxf, SKYLARK250_WALL-S_detailed.3dm, SKYLARK250_WALL-S_detailed.dwg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]
2022-03-04 v0.1.1 release - updates and fixes
    - Updated wall system blocks including fixing dimension error on notch for COMBs on all WALLs, CORNERs, DOORs and WINDOWs blocks.
    - NEW WALL-G blocks have been added for gable roof end walls
    - Bow-tie and peg models and cutting files now added
    - Design Kit has now been updated with both simple and detailed models.
    - NEW Example chassis models showing how blocks can be assembled now available as part of simple and detailed Design Kits
    - back-saved library model files to Sketchup 2017 and Rhino 6 (for those using legacy software)
    [SKYLARK250 block list.xlsx, SKYLARK250_COMB-B_END-Y2_cnc.dxf, SKYLARK250_COMB-G_END-X1_cnc.dxf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]
2022-03-04 Block list copied into repo
    [SKYLARK250 block list.xlsx]
2022-03-07 Corrected misaligned component in END-S simple block
    [SKYLARK250_END-S_simple.skp, SKYLARK250_design-kit_blocks_simple.skp]
2022-03-11 Fixed default materials and block names, added IFC and Blender components
    [SKYLARK250_design-kit_blocks_simple.blend, SKYLARK250_design-kit_blocks_simple.skp, SKYLARK250_design-kit_chassis_simple.skp]
2022-03-23 Fixed outdated cnc files to match v0.1.1 VERGE-G detailed model
    [SKYLARK250_VERGE-G_cnc.dxf]
2022-03-24 Patch to fix various issues
    - SKYLARK250_COMB-A/END simple models
    - Design kit models updated
    - END-L geometry issues resolved
    [SKYLARK250_COMB-A_END-X1_simple.3dm, SKYLARK250_COMB-A_END-X2_simple.3dm, SKYLARK250_COMB-A_END-X3_simple.3dm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]
2022-05-18 Fix to part 1D
    Added missing notches for bow-ties
    [SKYLARK250_END-L_cnc.dxf]
2022-06-21 Corrected naming issue
    Rename from CORNER-M to CORNER-S
    [SKYLARK250_CORNER-S_cnc.dxf]
2022-07-27 Corrected all floor block widths to precisely 600mm
    Fixed issue with Simple floor blocks being ~0.25mm too wide
    [SKYLARK250_design-kit_blocks_simple.blend, SKYLARK250_design-kit_blocks_simple.skp, SKYLARK250_design-kit_chassis_simple.skp]
2022-08-05 SKYLARK200 series initial commit
    Initial commit containing SKYLARK200 detailed blocks
    [SKYLARK150_COMB-F_END-X1.3dm, SKYLARK150_COMB-F_END-X1.dwg, SKYLARK150_COMB-F_END-X1.skp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]
2022-08-06 CNC cutting files added
    [SKYLARK150_END-XXS_cnc.dxf, SKYLARK150_END-XXXS_cnc.dxf, SKYLARK150_FLOOR-XXS_cnc.dxf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]
2022-08-10 Added standard door opening blocks
    [SKYLARK200_DOOR-L1.3dm, SKYLARK200_DOOR-L1.dwg, SKYLARK200_DOOR-L1.skp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]
2022-09-02 CNC cutting files added
    COMB cnc dxf file added
    [SKYLARK150_COMB-F_END-X1.dxf, SKYLARK150_COMB-F_END-X2.dxf, SKYLARK150_COMB-F_END-X3.dxf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]
2022-09-12 Corrected missing row of bowties
    [SKYLARK200_CORNER-M.dwg, SKYLARK200_CORNER-M.skp, SKYLARK200_CORNER-M_cnc.dxf]
2022-09-12 Updated origin
    [SKYLARK200_CORNER-M.dwg, SKYLARK200_CORNER-M.skp]
2022-09-12 Fixed incorrect block in CORNER-M skp model
    [SKYLARK250_CORNER-M_detailed.skp]
2022-09-28 New SKYLARK200 window and door blocks added!
    [SKYLARK200_DOOR-L1.3dm, SKYLARK200_DOOR-L1.dwg, SKYLARK200_DOOR-L1.skp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]
2022-09-30 Chassis starter model added
    [SKYLARK200_design-kit_chassis_detailed.skp]
2022-10-04 200 pegs initial commit
    [SKYLARK200_PEG.3dm, SKYLARK200_PEG.dwg, SKYLARK200_PEG.skp]
2022-10-06 Bow tie corrections and additions
    [SKYLARK250_TIE.3dm, SKYLARK250_TIE.dwg, SKYLARK250_TIE.skp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]
2022-10-06 Fixed misaligned end panel
    [SKYLARK150_FLOOR-XXS.dwg, SKYLARK150_FLOOR-XXS.skp]
2022-10-07 Restructured design kit
    [SKYLARK200_design-kit_chassis_detailed.skp]
2022-10-10 Fix to corner blocks
    Matched bowtie locations to wall blocks
    [SKYLARK200_CORNER-L.dwg, SKYLARK200_CORNER-L.skp, SKYLARK200_CORNER-L_cnc.dxf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]
2022-10-10 Reorganised design kit by file type
    [SKYLARK200_design-kit_chassis_detailed.skp]
2022-10-10 Reorganised design kit folder paths
    [SKYLARK250 block list.xlsx]
2022-10-10 Reorganised design kit simple folder paths
    [SKYLARK250 block list.xlsx, SKYLARK250_design-kit_blocks_simple.blend, SKYLARK250_design-kit_blocks_simple.skp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]
2022-10-10 Corrected mismatched file names on Combs
    [SKYLARK150_COMB-F_END-X1.dxf, SKYLARK150_COMB-F_END-X2.dxf, SKYLARK150_COMB-F_END-X3.dxf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]
2023-02-24 v0.2.0 public release initial commit
    [SKYLARK150_COMB-F_END-X1.3dm, SKYLARK150_COMB-F_END-X1.dwg, SKYLARK150_COMB-F_END-X1.dxf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]
2023-02-28 Skylark v0.2.0 upgrade commit
    [SKYLARK200_CORNER-L.dwg, SKYLARK200_CORNER-L.skp, SKYLARK200_CORNER-M.dwg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]
2023-03-01 Update the design kit with lfs for both 200 and 250 (#6)
    [SKYLARK200_design-kit_blocks_detailed.3dm, SKYLARK200_design-kit_blocks_detailed.blend, SKYLARK250_design-kit_blocks_detailed.3dm]
2023-03-02 Corrected series to 250
    [SKYLARK250_CORNER-L.dwg, SKYLARK250_CORNER-L.skp, SKYLARK250_CORNER-M.dwg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]
2023-03-03 Fixed file naming error
    [SKYLARK200_ROOF-42-S.dwg, SKYLARK200_ROOF-42-S.skp, SKYLARK200_ROOF-42-XS.dwg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]
2023-03-03 Bowtie models added
    [SKYLARK200_TIES.3dm, SKYLARK200_TIES.dwg, SKYLARK200_TIES.skp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]
2023-04-13 CNC cutting files and images added for 250 series
    [SKYLARK250_CORNER-L_cnc.dxf, SKYLARK250_CORNER-M_cnc.dxf, SKYLARK250_CORNER-S_cnc.dxf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]
2023-04-14 CNC cutting files and images added for 250 series openings
    [SKYLARK250_DOOR-L1_cnc.dxf, SKYLARK250_DOOR-M1_cnc.dxf, SKYLARK250_DOOR-S1_cnc.dxf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]
2023-08-10 v0.2.1 update including CNC files, fixes, and pitched roof ridge beam details
    [SKYLARK200_CORNER-L.dwg, SKYLARK200_CORNER-L.skp, SKYLARK200_CORNER-L_cnc.dxf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]
2023-08-11 upload large files
    [SKYLARK200_design-kit_blocks_detailed.3dm, SKYLARK200_design-kit_blocks_detailed.blend, SKYLARK200_design-kit_blocks_detailed.skp]
2023-08-17 Skylark200 Simple blocks design kit added
    [SKYLARK200_design-kit_blocks_simple.dwg, SKYLARK200_design-kit_blocks_simple.skp]
2023-08-23 Fixed incorrect end blocks in END-S-0 to END-XXXS-0 beams
    [SKYLARK200_design-kit_blocks_simple.dwg, SKYLARK200_design-kit_blocks_simple.skp]
2024-01-05 Fixed file naming issue
    [SKYLARK250_WALL-M42-5R.dwg, SKYLARK250_WALL-M42-5R.skp, SKYLARK250_WALL-M42-5R_cnc.dxf]
2024-01-25 v0.2.2 commit
    [SKYLARK150_FLOOR-XXS.dwg, SKYLARK150_FLOOR-XXXS.dwg, SKYLARK150_ROOF-XXS.dwg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]
2024-01-26 Design kit update (#8)
    * fixed clash on SKYLARK250_WALL-S10+1 and SKYLARK250_WALL-S10-1
    * update the design kit (simple and detailed) for Rhino and for Sktechup
    ---------
    [SKYLARK200_design-kit_blocks_detailed.3dm, SKYLARK200_design-kit_blocks_detailed.skp, SKYLARK200_design-kit_blocks_simple.skp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]
2024-01-31 update all the design kit files (#9)
    [SKYLARK200_design-kit_blocks_detailed.blend, SKYLARK200_design-kit_blocks_detailed.dwg, SKYLARK200_design-kit_blocks_detailed.skp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]
2024-02-13 Corrected block names on beams, ends, and verges
    [SKYLARK250_design-kit_blocks_simple.skp]
2024-03-07 Fixes to Verge cutting files and mirrored blocks added
    - Corrected missing parts and clashes on cutting files
    - Added mirrored/handed versions of verge blocks and cutting files (+)
    [SKYLARK200_VERGE+S.dwg, SKYLARK200_VERGE+S_cnc.dxf, SKYLARK200_VERGE+XS.dwg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]
2024-04-18 Design types initial commit
    [WikiHouse_garden-studio_BoM.xlsx, WikiHouse_micro-house_BoM.xlsx, WikiHouse_switch-house_BoM.xlsx]
2024-08-22 Skylark Version 0.2.2 (#14)
    * add new 200 blocks + fixes
    * add new 250 blocks + fixes
    * update 200 design kit
    * update 250 design kit
    * update 250-WALL-S10+
    * update 250-ROOF-XXS10
    * update 250 windows
    * update iso S+ walls and G42 wall
    * update 200 verge isos
    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
    [SKYLARK150_FLOOR-XXS.dwg, SKYLARK150_FLOOR-XXXS.dwg, SKYLARK150_ROOF-XXS.dwg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]
2026-10-01 Minor corrections and fixes across most blocks
    Corrected labelling, minor geometry clashes, and toolpath issues across the Skylark150 blocks and CNC files
    [C-L-1-A.dxf, C-L-1-B.dxf, C-L-1-C.dxf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]
2026-10-08 Minor clash corrected in F-S and F-L webs
    [F-L-H.dxf, F-L.3dm, F-L.dwg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]
2026-10-09 Fixes to 3D model geometry in F-XXS and F-S
    [F-L.3dm, F-L.dwg, F-L.skp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]
2026-11-05 Simple Blocks Library and Design Kits added
    The design kit contains low-poly versions of all the standard Skylark blocks in several CAD formats.
